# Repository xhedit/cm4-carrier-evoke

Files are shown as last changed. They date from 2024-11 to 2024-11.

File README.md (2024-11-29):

# "Evoke" CM4 Carrier Board

This is a breakout board for a CM4, maybe suitable for a DIY tablet. The original intent was a modular product, but it never happened due to component shortages. Maybe someone will find it useful.

Todo: Switch the PCIe slot to a better use of the lanes, like USB 3. TUSB7320 or UPD720202K8 is readibly available now.

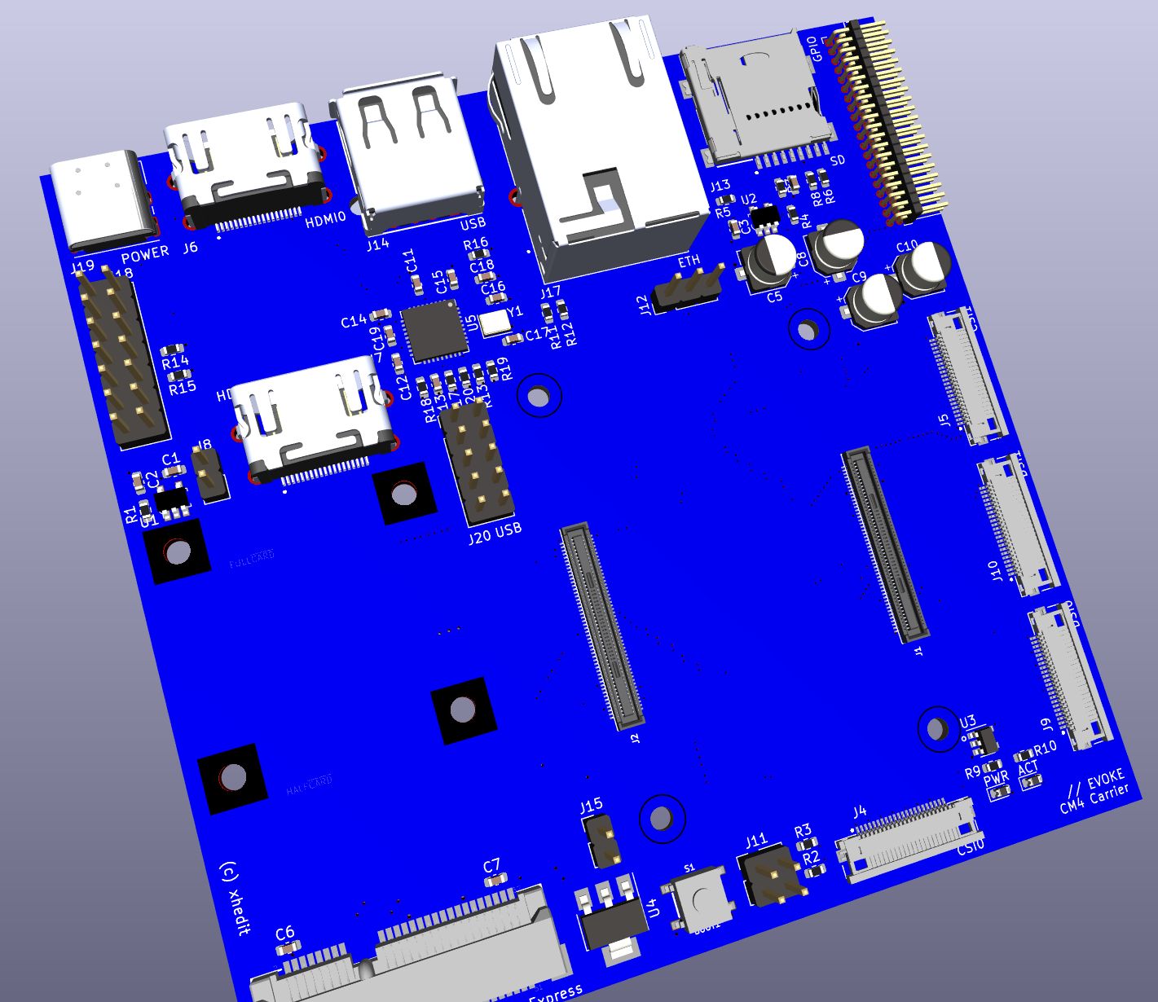
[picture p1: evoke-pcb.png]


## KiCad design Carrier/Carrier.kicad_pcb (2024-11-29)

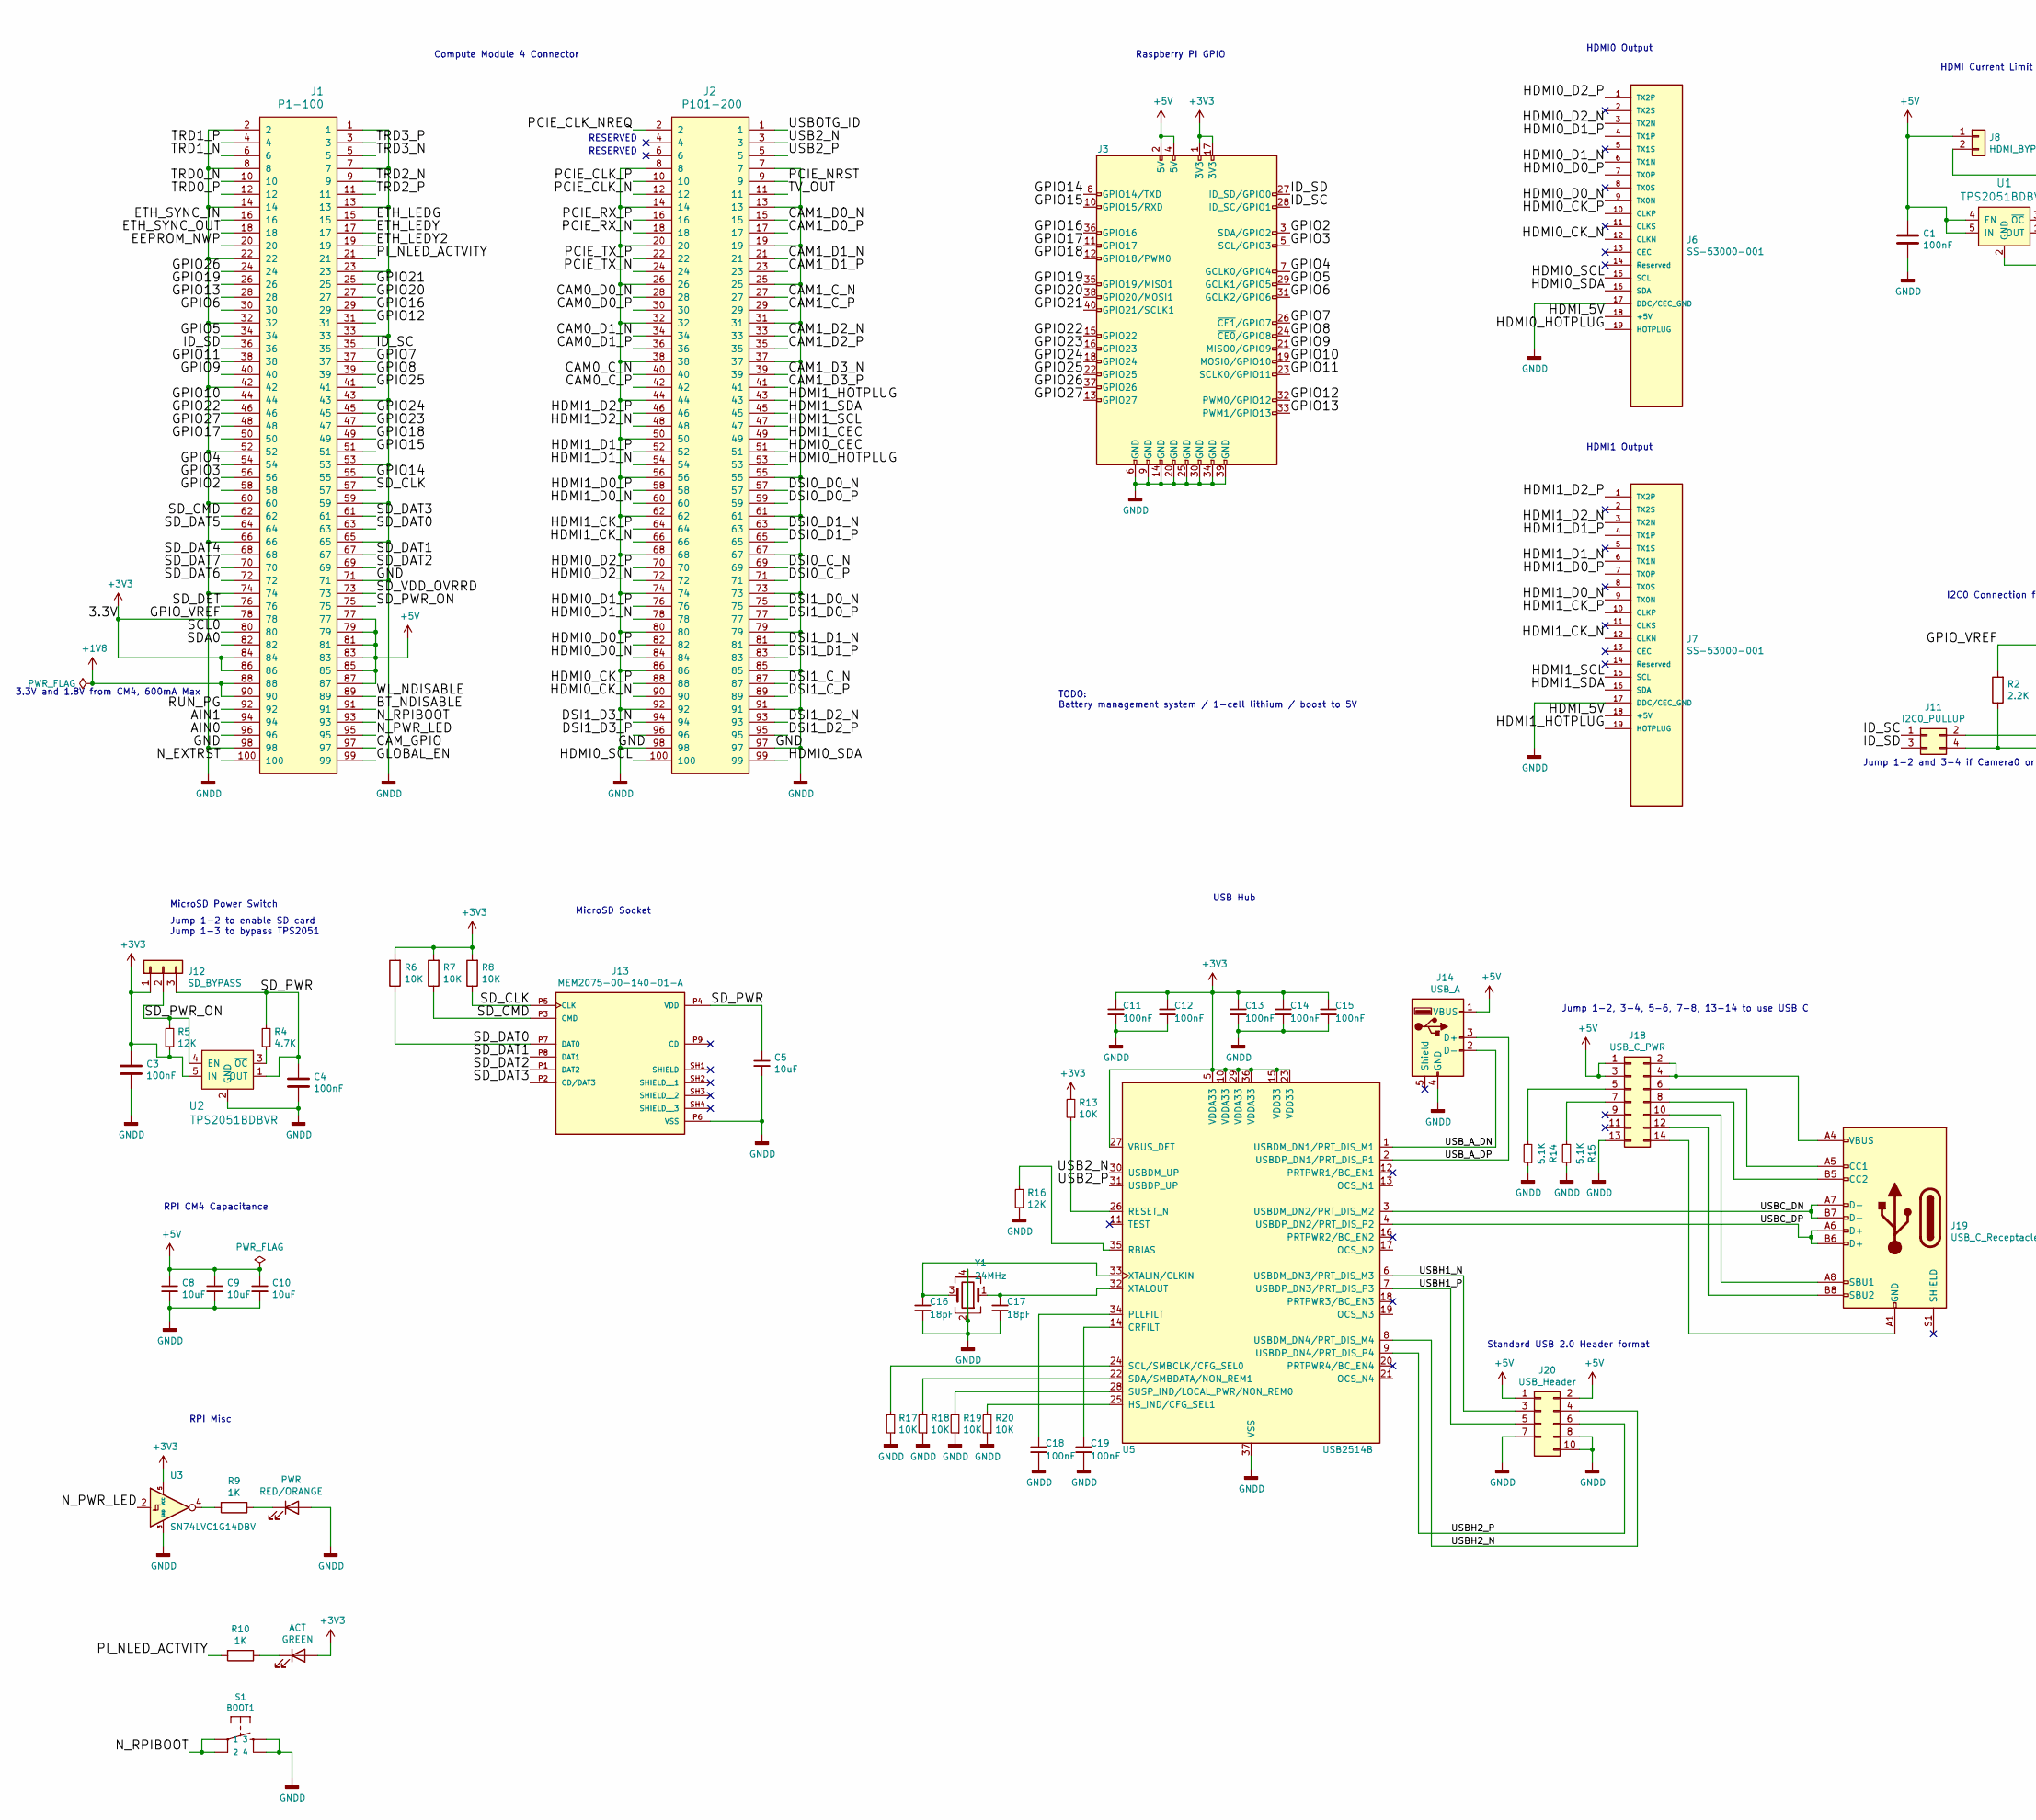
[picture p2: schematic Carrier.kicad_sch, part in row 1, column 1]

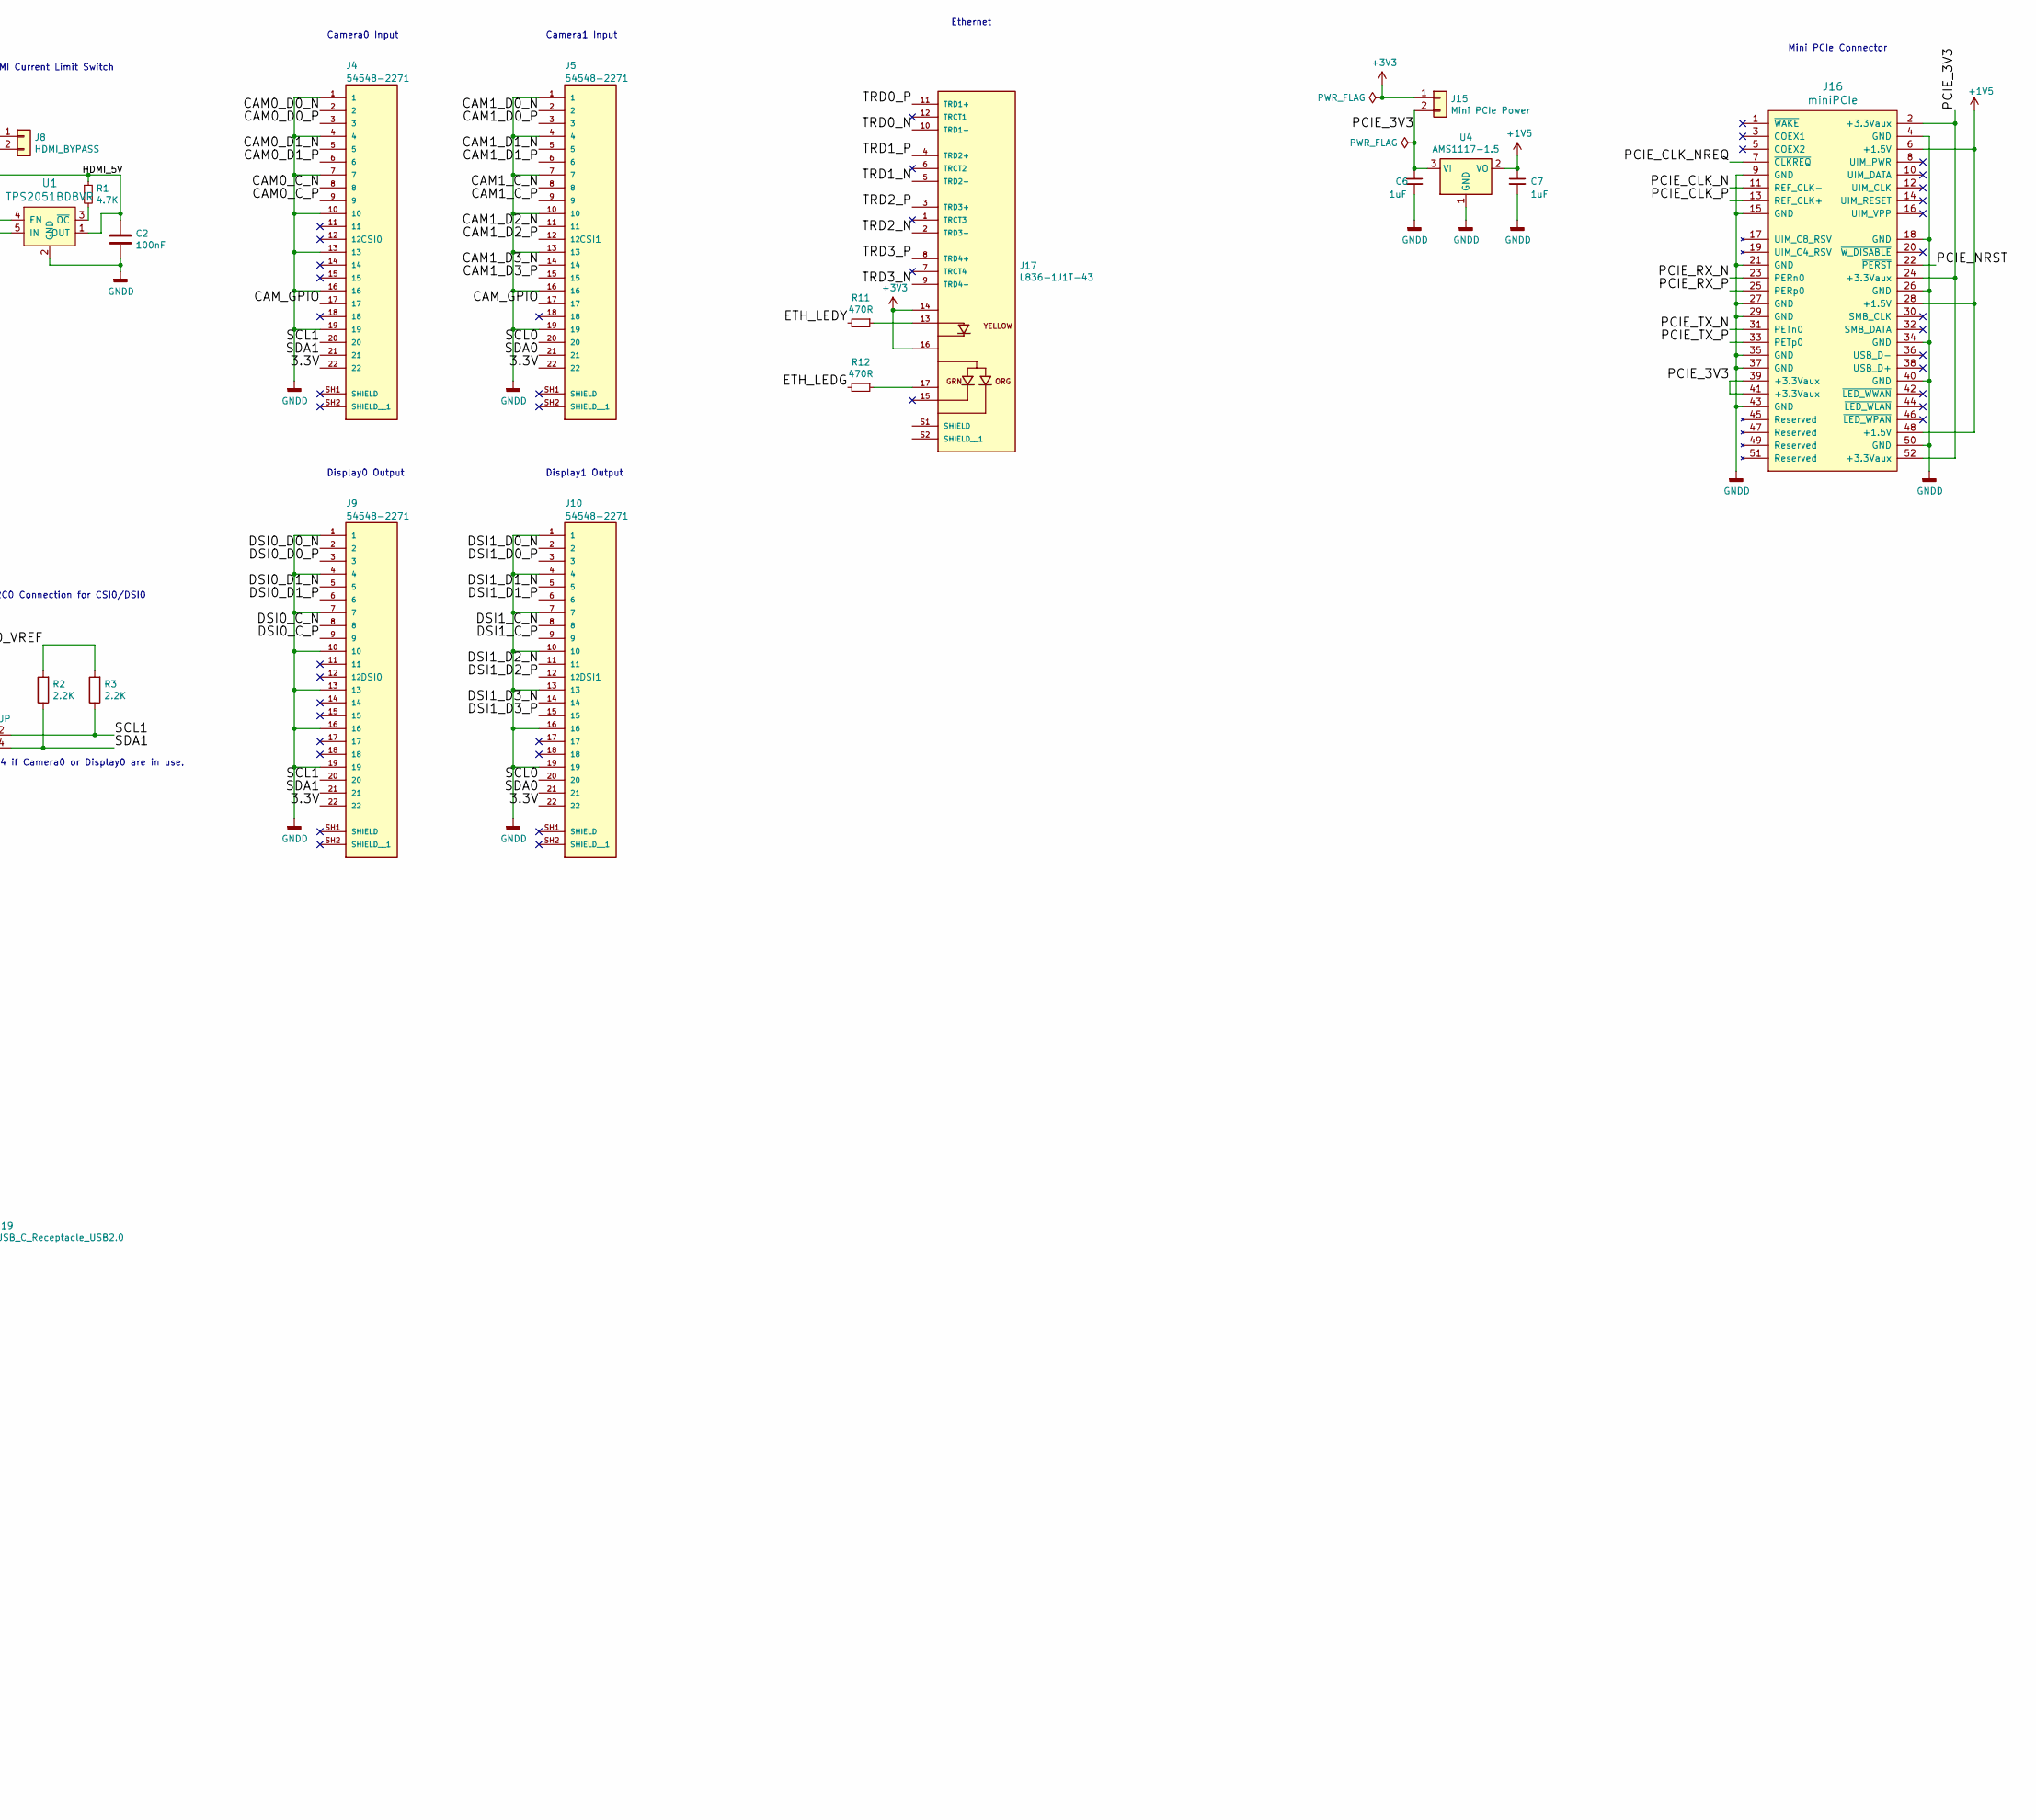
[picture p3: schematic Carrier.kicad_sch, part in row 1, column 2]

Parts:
ACT: GREEN; D_0603_1608Metric
C1, C2, C3, C4, C11, C12, C13, C14, C15, C18, C19: 100nF; C_0603_1608Metric
C5, C8, C9, C10: 10uF; CP_Elec_5x4.5
C6, C7: 1uF; C_0603_1608Metric
C16, C17: 18pF; C_0603_1608Metric
J1: P1-100; HRS_DF40C-100DS-0.4V(51)
J2: P101-200; HRS_DF40C-100DS-0.4V(51)
J3: Pi GPIO; PinHeader_2x20_P1.27mm_Horizontal
J4, J5, J9, J10: 54548-2271; MOLEX_54548-2271; PARTREV N
J6, J7: SS-53000-001; STEWART_SS-53000-001; PARTREV A0
J8: HDMI_BYPASS; PinHeader_1x02_P2.54mm_Vertical
J11: I2C0_PULLUP; PinHeader_2x02_P2.54mm_Vertical
J12: SD_BYPASS; PinHeader_1x03_P2.54mm_Vertical
J13: MEM2075-00-140-01-A; GCT_MEM2075-00-140-01-A; PARTREV A
J14: USB_A; OST_USB-A1HSW6
J15: Mini PCIe Power; PinHeader_1x02_P2.54mm_Vertical
J16: miniPCIe; TE_1775862-2
J17: L836-1J1T-43; BEL_L836-1J1T-43; PARTREV B
J18: USB_C_PWR; PinHeader_2x07_P2.54mm_Vertical
J19: USB_C_Receptacle_USB2.0; USB_C_Receptacle_GCT_USB4085
J20: USB_Header; PinHeader_2x05_P2.54mm_Vertical
PWR: RED/ORANGE; D_0603_1608Metric
R1, R4: 4.7K; R_0603_1608Metric
R2, R3: 2.2K; R_0603_1608Metric
R5, R16: 12K; R_0603_1608Metric
R6, R7, R8, R13, R17, R18, R19, R20: 10K; R_0603_1608Metric
R9, R10: 1K; R_0603_1608Metric
R11, R12: 470R; R_0603_1608Metric
R14, R15: 5.1K; R_0603_1608Metric
S1: BOOT1; TACTILE_SWITCH_SMD_5.2MM
U1, U2: TPS2051BDBVR; SOT-753; MPN TPS2051BDBVR; Digi-Key_PN 296-21265-1-ND
U3: SN74LVC1G14DBV; SOT-23-5
U4: AMS1117-1.5; SOT-223-3_TabPin2
U5: USB2514B; QFN-36-1EP_6x6mm_P0.5mm_EP3.7x3.7mm
Y1: 24MHz; Crystal_SMD_2520-4Pin_2.5x2.0mm

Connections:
+1V5: C7.1, J16.6 (+1.5V), J16.28 (+1.5V), J16.48 (+1.5V), U4.2 (VO)
+1V8: J1.88, J1.90
+3V3: ACT.2 (A), C3.1, C11.1, C12.1, C13.1, C14.1, C15.1, J1.78, J1.84, J1.86, J3.1 (3V3), J3.17 (3V3), J4.22, J5.22, J9.22, J10.22, J12.1, J15.1, J17.14, J17.16, R2.2, R3.2, R5.1, R6.2, R7.2, R8.2, R13.2, U2.5 (IN), U3.5 (VCC), U5.5 (VDDA33), U5.10 (VDDA33), U5.15 (VDD33), U5.23 (VDD33), U5.27 (VBUS_DET), U5.29 (VDDA33), U5.36 (VDDA33)
+5V: C1.1, C8.1, C9.1, C10.1, J1.77, J1.79, J1.81, J1.83, J1.85, J1.87, J3.2 (5V), J3.4 (5V), J8.1, J14.1 (VBUS), J18.1, J18.3, J20.1 (5V), J20.2 (5V), U1.4 (EN), U1.5 (IN)
/AIN0: J1.96
/AIN1: J1.94
/BT_NDISABLE: J1.91
/CAM0_C_N: J2.40, J4.8
/CAM0_C_P: J2.42, J4.9
/CAM0_D0_N: J2.28, J4.2
/CAM0_D0_P: J2.30, J4.3
/CAM0_D1_N: J2.34, J4.5
/CAM0_D1_P: J2.36, J4.6
/CAM1_C_N: J2.27, J5.8
/CAM1_C_P: J2.29, J5.9
/CAM1_D0_N: J2.15, J5.2
/CAM1_D0_P: J2.17, J5.3
/CAM1_D1_N: J2.21, J5.5
/CAM1_D1_P: J2.23, J5.6
/CAM1_D2_N: J2.33, J5.11
/CAM1_D2_P: J2.35, J5.12
/CAM1_D3_N: J2.39, J5.14
/CAM1_D3_P: J2.41, J5.15
/CAM_GPIO: J1.97, J4.17, J5.17
/DSI0_C_N: J2.69, J9.8
/DSI0_C_P: J2.71, J9.9
/DSI0_D0_N: J2.57, J9.2
/DSI0_D0_P: J2.59, J9.3
/DSI0_D1_N: J2.63, J9.5
/DSI0_D1_P: J2.65, J9.6
/DSI1_C_N: J2.87, J10.8
/DSI1_C_P: J2.89, J10.9
/DSI1_D0_N: J2.75, J10.2
/DSI1_D0_P: J2.77, J10.3
/DSI1_D1_N: J2.81, J10.5
/DSI1_D1_P: J2.83, J10.6
/DSI1_D2_N: J2.93, J10.11
/DSI1_D2_P: J2.95, J10.12
/DSI1_D3_N: J2.94, J10.14
/DSI1_D3_P: J2.96, J10.15
/EEPROM_NWP: J1.20
/ETH_LEDG: J1.15, R12.2
/ETH_LEDY: J1.17, R11.2
/ETH_LEDY2: J1.19
/ETH_SYNC_IN: J1.16
/ETH_SYNC_OUT: J1.18
/GLOBAL_EN: J1.99
/GPIO2: J1.58, J3.3 (SDA/GPIO2)
/GPIO3: J1.56, J3.5 (SCL/GPIO3)
/GPIO4: J1.54, J3.7 (GCLK0/GPIO4)
/GPIO5: J1.34, J3.29 (GCLK1/GPIO5)
/GPIO6: J1.30, J3.31 (GCLK2/GPIO6)
/GPIO7: J1.37, J3.26 (~CE1/GPIO7)
/GPIO8: J1.39, J3.24 (~CE0/GPIO8)
/GPIO9: J1.40, J3.21 (MISO0/GPIO9)
/GPIO10: J1.44, J3.19 (MOSI0/GPIO10)
/GPIO11: J1.38, J3.23 (SCLK0/GPIO11)
/GPIO12: J1.31, J3.32 (PWM0/GPIO12)
/GPIO13: J1.28, J3.33 (PWM1/GPIO13)
/GPIO14: J1.55, J3.8 (GPIO14/TXD)
/GPIO15: J1.51, J3.10 (GPIO15/RXD)
/GPIO16: J1.29, J3.36 (GPIO16)
/GPIO17: J1.50, J3.11 (GPIO17)
/GPIO18: J1.49, J3.12 (GPIO18/PWM0)
/GPIO19: J1.26, J3.35 (GPIO19/MISO1)
/GPIO20: J1.27, J3.38 (GPIO20/MOSI1)
/GPIO21: J1.25, J3.40 (GPIO21/SCLK1)
/GPIO22: J1.46, J3.15 (GPIO22)
/GPIO23: J1.47, J3.16 (GPIO23)
/GPIO24: J1.45, J3.18 (GPIO24)
/GPIO25: J1.41, J3.22 (GPIO25)
/GPIO26: J1.24, J3.37 (GPIO26)
/GPIO27: J1.48, J3.13 (GPIO27)
/HDMI0_CEC: J2.51
/HDMI0_CK_N: J2.90, J6.12 (CLKN)
/HDMI0_CK_P: J2.88, J6.10 (CLKP)
/HDMI0_D0_N: J2.84, J6.9 (TX0N)
/HDMI0_D0_P: J2.82, J6.7 (TX0P)
/HDMI0_D1_N: J2.78, J6.6 (TX1N)
/HDMI0_D1_P: J2.76, J6.4 (TX1P)
/HDMI0_D2_N: J2.72, J6.3 (TX2N)
/HDMI0_D2_P: J2.70, J6.1 (TX2P)
/HDMI0_HOTPLUG: J2.53, J6.19 (HOTPLUG)
/HDMI0_SCL: J2.100, J6.15 (SCL)
/HDMI0_SDA: J2.99, J6.16 (SDA)
/HDMI1_CEC: J2.49
/HDMI1_CK_N: J2.66, J7.12 (CLKN)
/HDMI1_CK_P: J2.64, J7.10 (CLKP)
/HDMI1_D0_N: J2.60, J7.9 (TX0N)
/HDMI1_D0_P: J2.58, J7.7 (TX0P)
/HDMI1_D1_N: J2.54, J7.6 (TX1N)
/HDMI1_D1_P: J2.52, J7.4 (TX1P)
/HDMI1_D2_N: J2.48, J7.3 (TX2N)
/HDMI1_D2_P: J2.46, J7.1 (TX2P)
/HDMI1_HOTPLUG: J2.43, J7.19 (HOTPLUG)
/HDMI1_SCL: J2.47, J7.15 (SCL)
/HDMI1_SDA: J2.45, J7.16 (SDA)
/HDMI_5V: C2.1, J6.18 (+5V), J7.18 (+5V), J8.2, R1.1, U1.1 (OUT)
/ID_SC: J1.35, J3.28 (ID_SC/GPIO1), J11.1
/ID_SD: J1.36, J3.27 (ID_SD/GPIO0), J11.3
/N_EXTRST: J1.100
/N_PWR_LED: J1.95, U3.2
/N_RPIBOOT: J1.93, S1.1, S1.2
/PCIE_3V3: C6.1, J15.2, J16.2 (+3.3Vaux), J16.24 (+3.3Vaux), J16.39 (+3.3Vaux), J16.41 (+3.3Vaux), J16.52 (+3.3Vaux), U4.3 (VI)
/PCIE_CLK_N: J2.12, J16.11 (REF_CLK-)
/PCIE_CLK_NREQ: J2.2, J16.7 (~CLKREQ)
/PCIE_CLK_P: J2.10, J16.13 (REF_CLK+)
/PCIE_NRST: J2.9, J16.22 (~PERST)
/PCIE_RX_N: J2.18, J16.23 (PERn0)
/PCIE_RX_P: J2.16, J16.25 (PERp0)
/PCIE_TX_N: J2.24, J16.31 (PETn0)
/PCIE_TX_P: J2.22, J16.33 (PETp0)
/PI_NLED_ACTVITY: J1.21, R10.2
/RUN_PG: J1.92
/SCL0: J1.80, J5.20, J10.20
/SCL1: J4.20, J9.20, J11.2, R3.1
/SDA0: J1.82, J5.21, J10.21
/SDA1: J4.21, J9.21, J11.4, R2.1
/SD_CLK: J1.57, J13.P5 (CLK), R8.1
/SD_CMD: J1.62, J13.P3 (CMD), R7.1
/SD_DAT0: J1.63, J13.P7 (DAT0), R6.1
/SD_DAT1: J1.67, J13.P8 (DAT1)
/SD_DAT2: J1.69, J13.P1 (DAT2)
/SD_DAT3: J1.61, J13.P2 (CD/DAT3)
/SD_DAT4: J1.68
/SD_DAT5: J1.64
/SD_DAT6: J1.72
/SD_DAT7: J1.70
/SD_DET: J1.76
/SD_PWR: C4.1, C5.1, J12.3, J13.P4 (VDD), R4.1, U2.1 (OUT)
/SD_PWR_ON: J1.75, J12.2, R5.2, U2.4 (EN)
/SD_VDD_OVRRD: J1.73
/TRD0_N: J1.10, J17.10 (TRD1-)
/TRD0_P: J1.12, J17.11 (TRD1+)
/TRD1_N: J1.6, J17.5 (TRD2-)
/TRD1_P: J1.4, J17.4 (TRD2+)
/TRD2_N: J1.9, J17.2 (TRD3-)
/TRD2_P: J1.11, J17.3 (TRD3+)
/TRD3_N: J1.5, J17.9 (TRD4-)
/TRD3_P: J1.3, J17.8 (TRD4+)
/TV_OUT: J2.11
/USB2_N: J2.3, U5.30 (USBDM_UP)
/USB2_P: J2.5, U5.31 (USBDP_UP)
/USBC_DN: J19.A7 (D-), J19.B7 (D-), U5.3 (USBDM_DN2/PRT_DIS_M2)
/USBC_DP: J19.A6 (D+), J19.B6 (D+), U5.4 (USBDP_DN2/PRT_DIS_P2)
/USBH1_N: J20.3 (DM), U5.6 (USBDM_DN3/PRT_DIS_M3)
/USBH1_P: J20.5 (DP), U5.7 (USBDP_DN3/PRT_DIS_P3)
/USBH2_N: J20.4 (DM), U5.8 (USBDM_DN4/PRT_DIS_M4)
/USBH2_P: J20.6 (DP), U5.9 (USBDP_DN4/PRT_DIS_P4)
/USBOTG_ID: J2.1
/USB_A_DN: J14.2 (D-), U5.1 (USBDM_DN1/PRT_DIS_M1)
/USB_A_DP: J14.3 (D+), U5.2 (USBDP_DN1/PRT_DIS_P1)
/WL_NDISABLE: J1.89
GNDD: C1.2, C2.2, C3.2, C4.2, C5.2, C6.2, C7.2, C8.2, C9.2, C10.2, C11.2, C12.2, C13.2, C14.2, C15.2, C16.2, C17.2, C18.2, C19.2, J1.1, J1.2, J1.7, J1.8, J1.13, J1.14, J1.22, J1.23, J1.32, J1.33, J1.42, J1.43, J1.52, J1.53, J1.59, J1.60, J1.65, J1.66, J1.71, J1.74, J1.98, J2.7, J2.8, J2.13, J2.14, J2.19, J2.20, J2.25, J2.26, J2.31, J2.32, J2.37, J2.38, J2.44, J2.50, J2.55, J2.56, J2.61, J2.62, J2.67, J2.68, J2.73, J2.74, J2.79, J2.80, J2.85, J2.86, J2.91, J2.92, J2.97, J2.98, J3.6 (GND), J3.9 (GND), J3.14 (GND), J3.20 (GND), J3.25 (GND), J3.30 (GND), J3.34 (GND), J3.39 (GND), J4.1, J4.4, J4.7, J4.10, J4.13, J4.16, J4.19, J5.1, J5.4, J5.7, J5.10, J5.13, J5.16, J5.19, J6.17 (DDC/CEC_GND), J7.17 (DDC/CEC_GND), J9.1, J9.4, J9.7, J9.10, J9.13, J9.16, J9.19, J10.1, J10.4, J10.7, J10.10, J10.13, J10.16, J10.19, J13.P6 (VSS), J14.4 (GND), J16.4 (GND), J16.9 (GND), J16.15 (GND), J16.18 (GND), J16.21 (GND), J16.26 (GND), J16.27 (GND), J16.29 (GND), J16.34 (GND), J16.35 (GND), J16.37 (GND), J16.40 (GND), J16.43 (GND), J16.50 (GND), J18.13, J20.7 (GND), J20.8 (GND), J20.10 (NC), PWR.2 (A), R14.1, R15.1, R16.1, R17.1, R18.1, R19.1, R20.1, S1.3, S1.4, U1.2 (GND), U2.2 (GND), U3.3 (GND), U4.1 (GND), U5.37 (VSS), Y1.2, Y1.4
unnamed: ACT.1 (K), R10.1
unnamed: C16.1, U5.33 (XTALIN/CLKIN), Y1.3
unnamed: C17.1, U5.32 (XTALOUT), Y1.1
unnamed: C18.1, U5.34 (PLLFILT)
unnamed: C19.1, U5.14 (CRFILT)
unnamed: J17.13, R11.1
unnamed: J17.17, R12.1
unnamed: J18.2, J18.4, J19.A4 (VBUS), J19.A9 (VBUS), J19.B4 (VBUS), J19.B9 (VBUS)
unnamed: J18.5, R14.2
unnamed: J18.6, J19.A5 (CC1)
unnamed: J18.7, R15.2
unnamed: J18.8, J19.B5 (CC2)
unnamed: J18.10, J19.A8 (SBU1)
unnamed: J18.12, J19.B8 (SBU2)
unnamed: J18.14, J19.A1 (GND), J19.A12 (GND), J19.B1 (GND), J19.B12 (GND)
unnamed: PWR.1 (K), R9.1
unnamed: R1.2, U1.3 (~OC)
unnamed: R4.2, U2.3 (~OC)
unnamed: R9.2, U3.4
unnamed: R13.1, U5.26 (RESET_N)
unnamed: R16.2, U5.35 (RBIAS)
unnamed: R17.2, U5.24 (SCL/SMBCLK/CFG_SEL0)
unnamed: R18.2, U5.22 (SDA/SMBDATA/NON_REM1)
unnamed: R19.2, U5.28 (SUSP_IND/LOCAL_PWR/NON_REM0)
unnamed: R20.2, U5.25 (HS_IND/CFG_SEL1)

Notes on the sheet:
Compute Module 4 Connector
Mini PCIe Connector
Display0 Output
I2C0 Connection for CSI0/DSI0
HDMI Current Limit Switch
RESERVED
HDMI0 Output
Ethernet
3.3V and 1.8V from CM4, 600mA Max
Jump 1-2 and 3-4 if Camera0 or Display0 are in use.
Camera1 Input
Display1 Output
RPI CM4 Capacitance
Camera0 Input
Standard USB 2.0 Header format
MicroSD Socket
Jump 1-2, 3-4, 5-6, 7-8, 13-14 to use USB C
HDMI1 Output
MicroSD Power Switch
TODO: Battery management system / 1-cell lithium / boost to 5V
RPI Misc
USB Hub
Raspberry PI GPIO
Jump 1-2 to enable SD card Jump 1-3 to bypass TPS2051

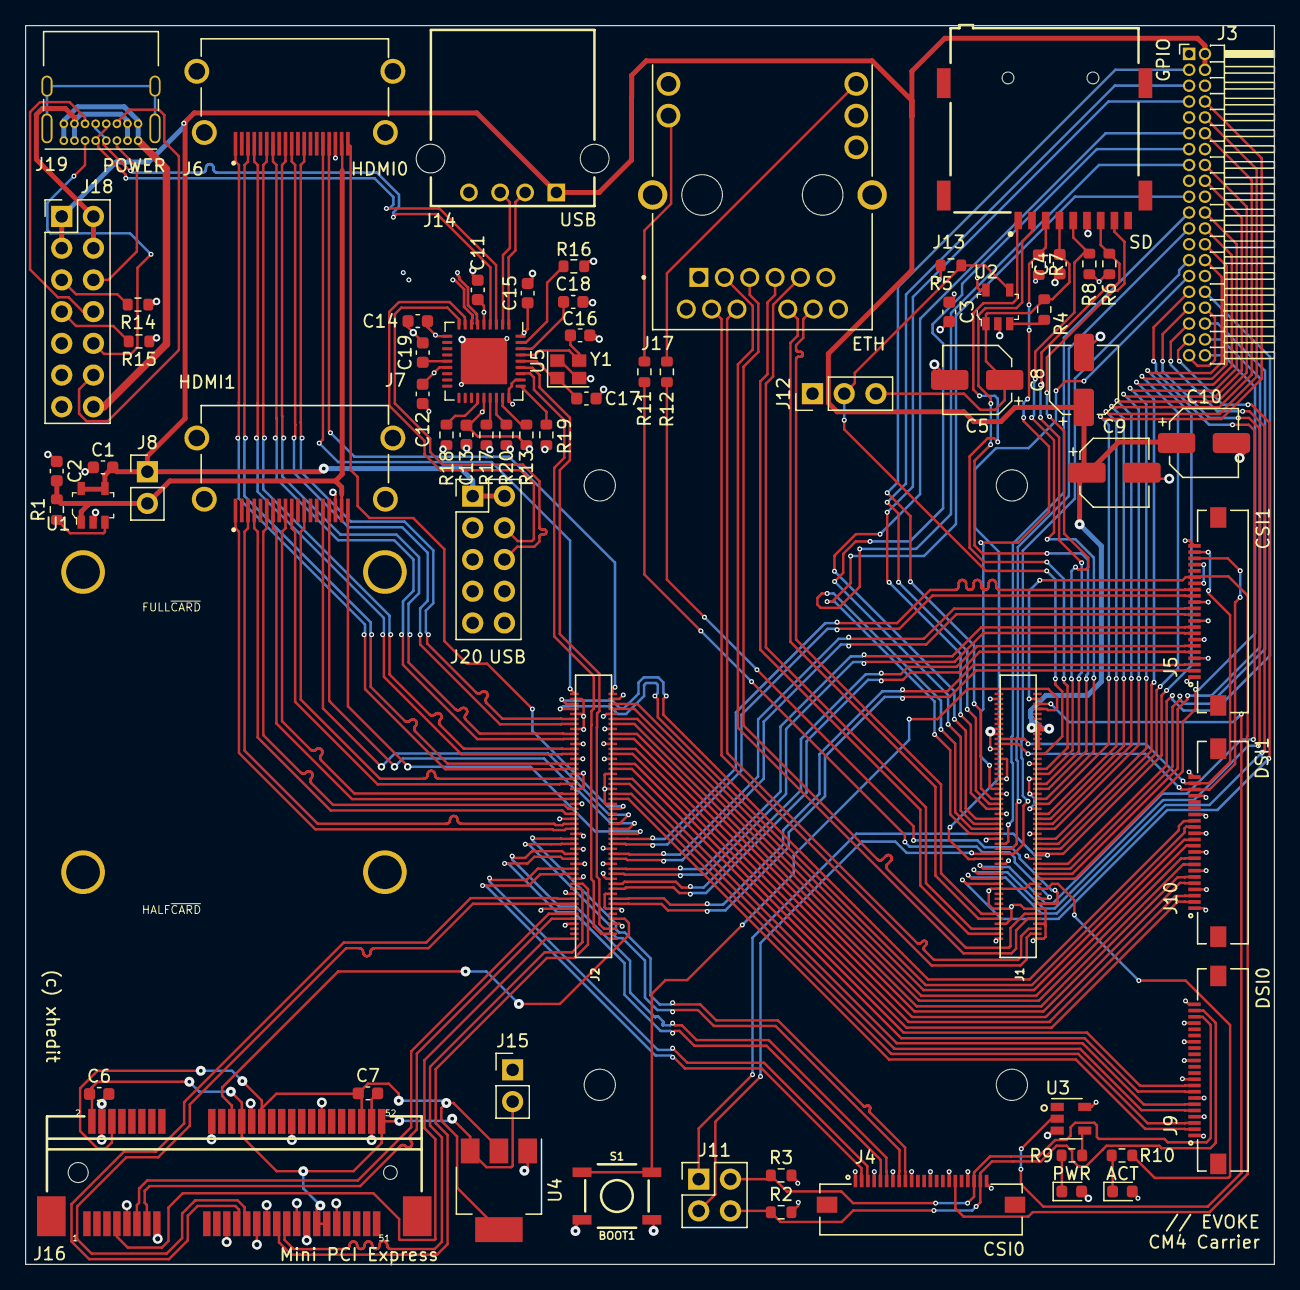
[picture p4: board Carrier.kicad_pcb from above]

Board: 4 copper layers, 100.0 x 99.2 mm, 72 parts (0 on the bottom side), 158 nets.

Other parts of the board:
M1, M2, M3, M4: MountingHole_2.5mm

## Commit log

2024-11-29 add kicad proj files
    [Carrier.kicad_pcb, Carrier.kicad_sch]
2024-11-29 add board view
